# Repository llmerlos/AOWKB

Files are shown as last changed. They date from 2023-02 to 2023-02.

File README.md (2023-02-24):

# An Otter Keyboard

Personal project to develop a ergonomic split wireless/wired keyboard. Firmware for the wireless version can be found in [https://github.com/llmerlos/zmk-config-aokb]



## Keyboard specifications:
### Wireless:
* 2x PCB (reversible)
* 2x Switch Plate (reversible)
* 2x Seeed Studio XIAO NRF52840
* 2x MSK-12C02 switch
* 2x 51021 JST 1.25mm 2P Battery Connector
* 2x LiPo Battery 402535 3.7V 320mAh
* 40x IN4148W SOD-123 Diodes
* 40x Kail Choc Switches
* 40x Kail Choc Keycaps
* 40x Kail Chos Hotswap Sockets
* 12x M3 4mm Screws and Nuts

### Wired:
* 2x PCB (reversible)
* 2x Switch Plate (reversible)
* 2x Seeed Studio XIAO RP2040
* 2x TRRS-PJ-320A connector
* 40x IN4148W SOD-123 Diodes
* 40x Kail Choc Switches
* 40x Kail Choc Keycaps
* 40x Kail Chos Hotswap Sockets
* 12x M3 4mm Screws and Nuts

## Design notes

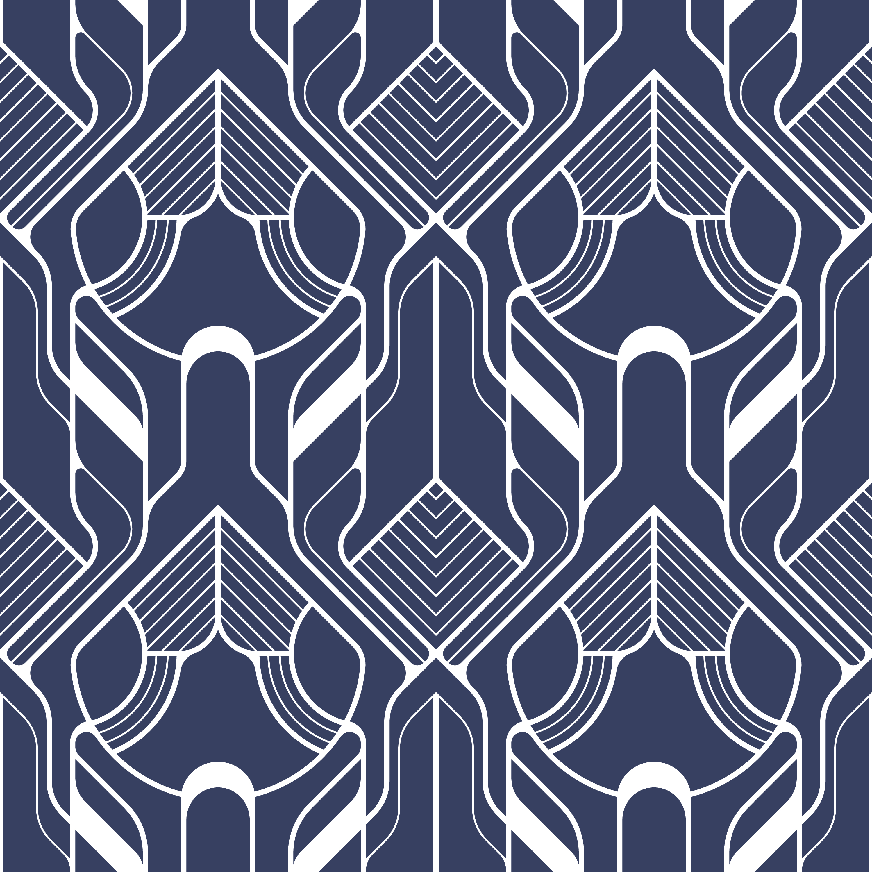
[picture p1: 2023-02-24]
PCB/vectorstock_41117463/vectorstock_41117463/vectorstock_41117463.jpg

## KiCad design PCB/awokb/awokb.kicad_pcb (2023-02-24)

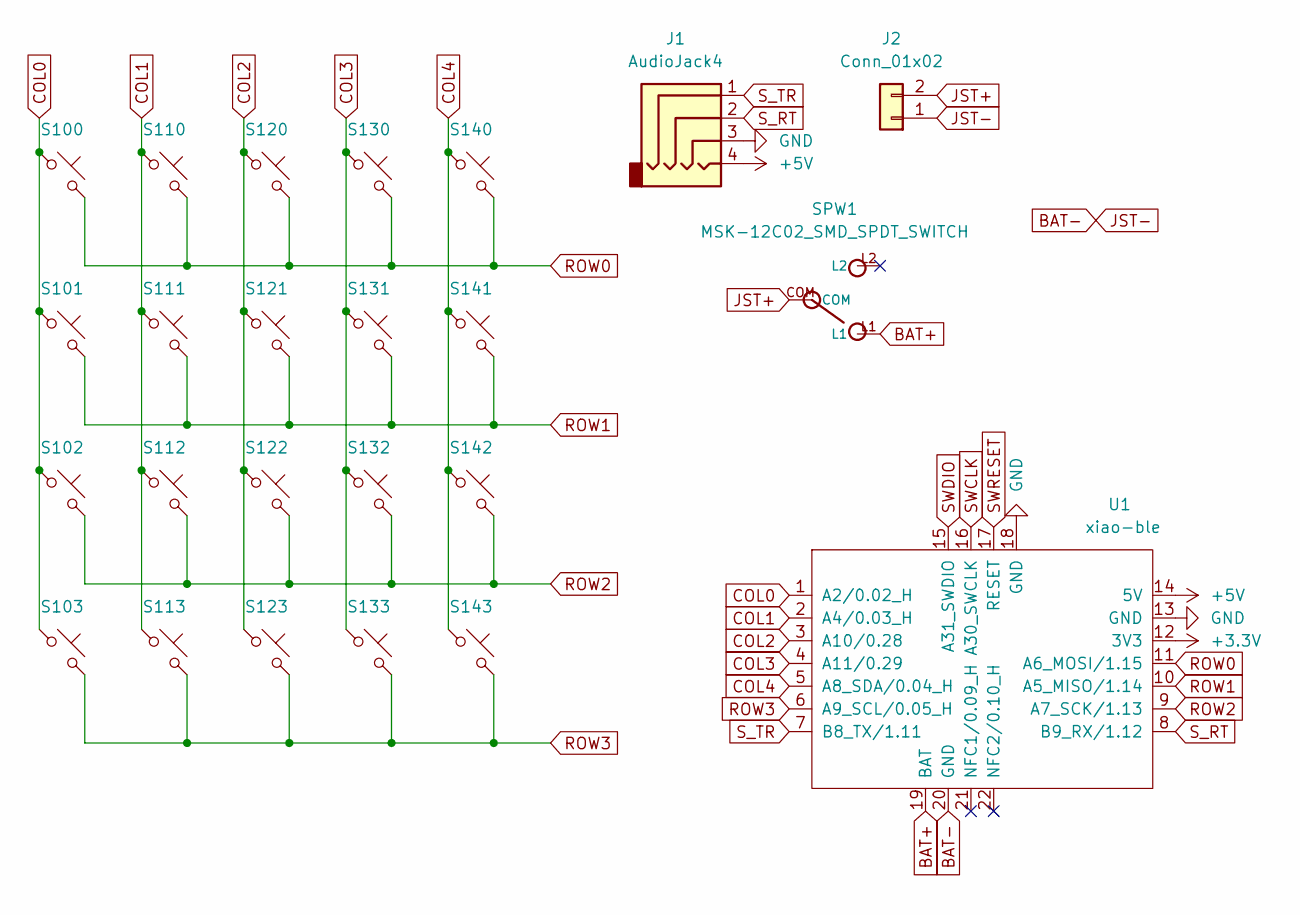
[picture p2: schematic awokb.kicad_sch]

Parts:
J1: AudioJack4; TRRS-PJ-320A_Mirr
J2: Conn_01x02; JST_PH_B2B-PH-K_1x02_P2.00mm_Vertical
S100, S101, S102, S103, S110, S111, S112, S113, S120, S121, S122, S123, S130, S131, S132, S133, S140, S141, S142, S143: SW_Push_45deg; Choc_HS_R_SOD
SPW1: MSK-12C02_SMD_SPDT_SWITCH; MSK-12C02
U1: xiao-ble; xiao-ble-smd_r

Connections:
+3V3: U1.12 (3V3)
+5V: J1.4, U1.14 (5V)
BAT+: SPW1.L1, U1.19 (BAT)
BAT-: J2.1, U1.20 (GND)
COL0: S100.1, S101.1, S102.1, S103.1, U1.1 (A2/0.02_H)
COL1: S110.1, S111.1, S112.1, S113.1, U1.2 (A4/0.03_H)
COL2: S120.1, S121.1, S122.1, S123.1, U1.3 (A10/0.28)
COL3: S130.1, S131.1, S132.1, S133.1, U1.4 (A11/0.29)
COL4: S140.1, S141.1, S142.1, S143.1, U1.5 (A8_SDA/0.04_H)
GND: J1.3, U1.13 (GND), U1.18 (GND)
JST+: J2.2, SPW1.COM
ROW0: S100.2, S110.2, S120.2, S130.2, S140.2, U1.11 (A6_MOSI/1.15)
ROW1: S101.2, S111.2, S121.2, S131.2, S141.2, U1.10 (A5_MISO/1.14)
ROW2: S102.2, S112.2, S122.2, S132.2, S142.2, U1.9 (A7_SCK/1.13)
ROW3: S103.2, S113.2, S123.2, S133.2, S143.2, U1.6 (A9_SCL/0.05_H)
SWCLK: U1.16 (A30_SWCLK)
SWDIO: U1.15 (A31_SWDIO)
SWRESET: U1.17 (RESET)
S_RT: J1.2, U1.8 (B9_RX/1.12)
S_TR: J1.1, U1.7 (B8_TX/1.11)

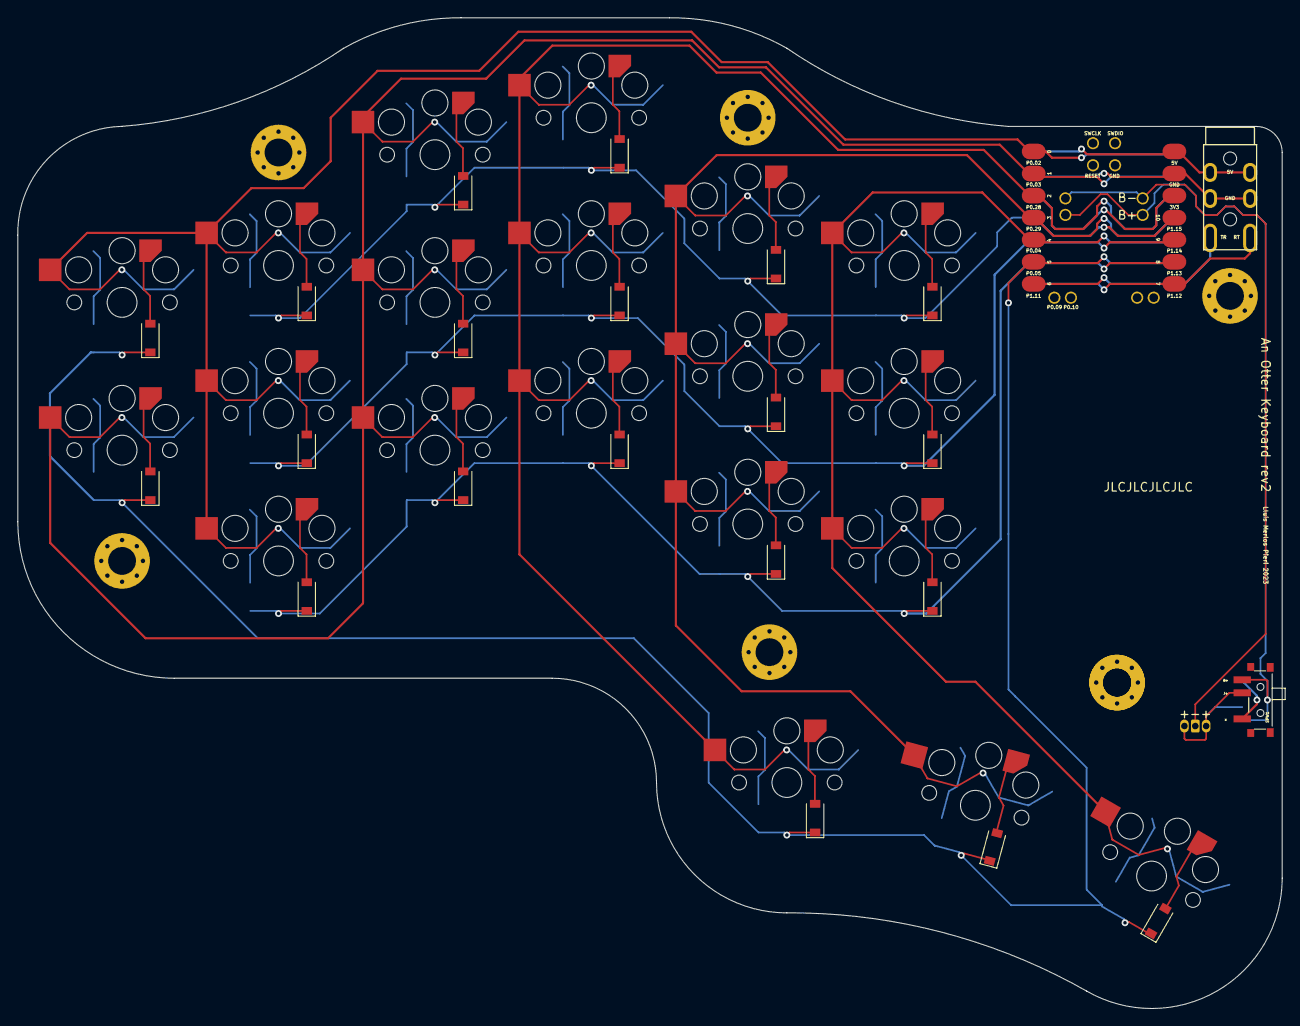
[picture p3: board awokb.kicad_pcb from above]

Board: 2 copper layers, 145.5 x 114.0 mm, 24 parts (0 on the bottom side), 16 nets.

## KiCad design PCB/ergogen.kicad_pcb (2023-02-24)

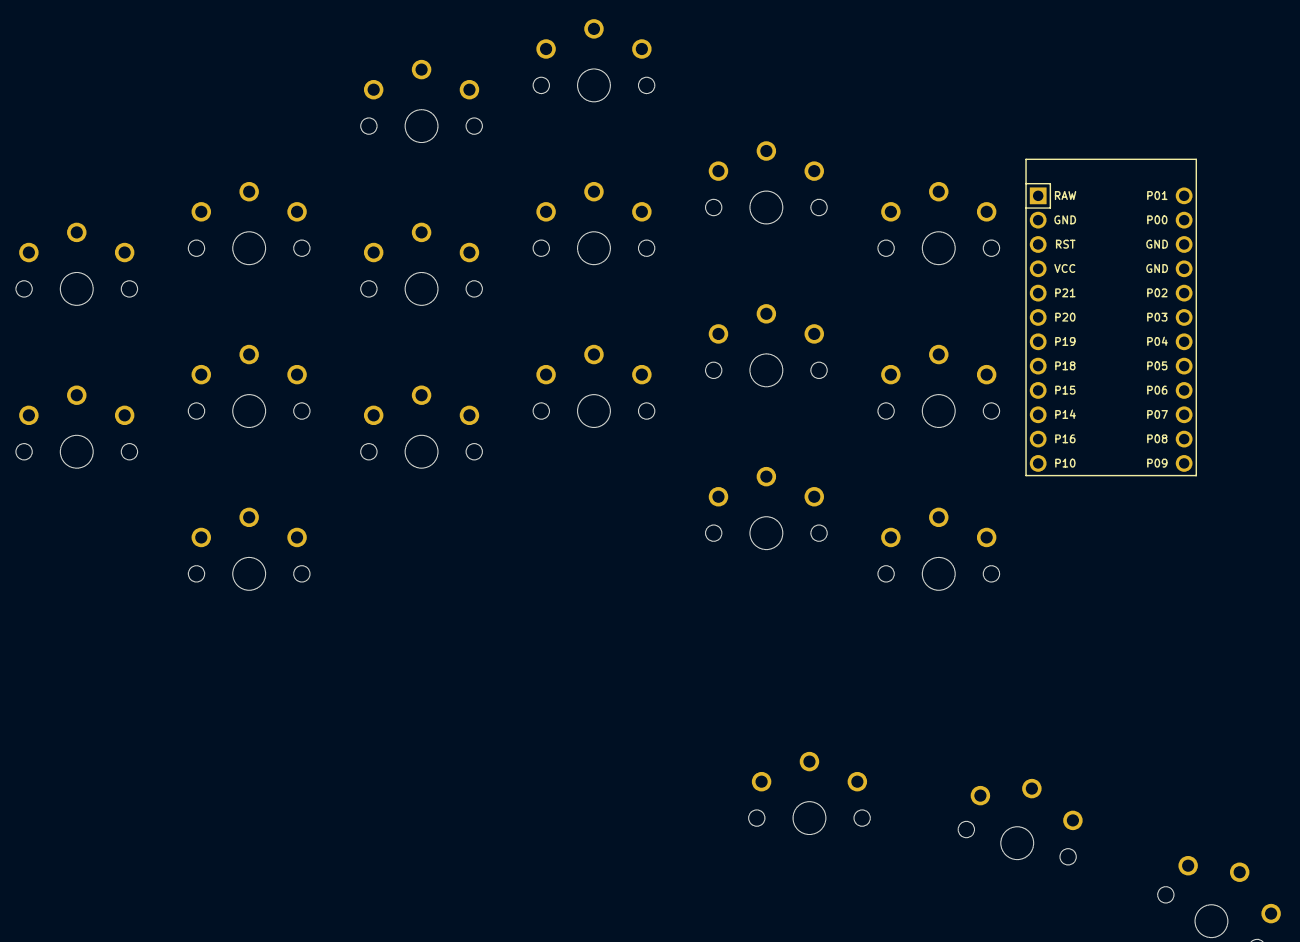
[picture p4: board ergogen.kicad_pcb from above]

Board: 2 copper layers, 21 parts (0 on the bottom side), 18 nets, no tracks yet.

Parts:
MCU1: ProMicro
S1, S2, S3, S4, S5, S6, S7, S8, S9, S10, S11, S12, S13, S14, S15, S16, S17, S18, S19, S20: PG1350

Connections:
GND: MCU1.2, MCU1.15, MCU1.16, S1.1, S2.1, S3.1, S4.1, S5.1, S6.1, S7.1, S8.1, S9.1, S10.1, S11.1, S12.1, S13.1, S14.1, S15.1, S16.1, S17.1, S18.1, S19.1, S20.1
matrix_index_bottom: MCU1.20, S10.2
matrix_index_home: MCU1.12, S11.2
matrix_index_top: MCU1.6, S12.2
matrix_inner_bottom: MCU1.21, S13.2
matrix_inner_home: MCU1.13, S14.2
matrix_inner_top: MCU1.5, S15.2
matrix_middle_bottom: MCU1.19, S7.2
matrix_middle_home: MCU1.11, S8.2
matrix_middle_top: MCU1.7, S9.2
matrix_pinky_bottom: MCU1.17, S1.2
matrix_pinky_home: MCU1.9, S2.2
matrix_pinky_top: MCU1.22, S3.2
matrix_ring_bottom: MCU1.18, S4.2
matrix_ring_home: MCU1.10, S5.2
matrix_ring_top: MCU1.8, S6.2
thumb_reachy: MCU1.24, S19.2
thumb_tucky: MCU1.23, S18.2
